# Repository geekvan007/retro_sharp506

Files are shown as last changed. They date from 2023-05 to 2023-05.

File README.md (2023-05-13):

# retro_sharp506
Retro an old-school calculator, using LED and mechanical keyboard

For several years, I am seeking a scientific calculator with a big screen
and keyboard but never found, so I decide to make a retro one.

It's not an emulator but a "real" machine, wish you like it.


[Full image](https://postimg.cc/0rZ6tzN7)


[Full image](https://postimg.cc/KRz1CmKw)


[Full image](https://postimg.cc/crbvSPwH)


[Full image](https://postimg.cc/rDRKFgN9)

[and here is the video](https://www.youtube.com/shorts/Iv_z6_ydeSI)

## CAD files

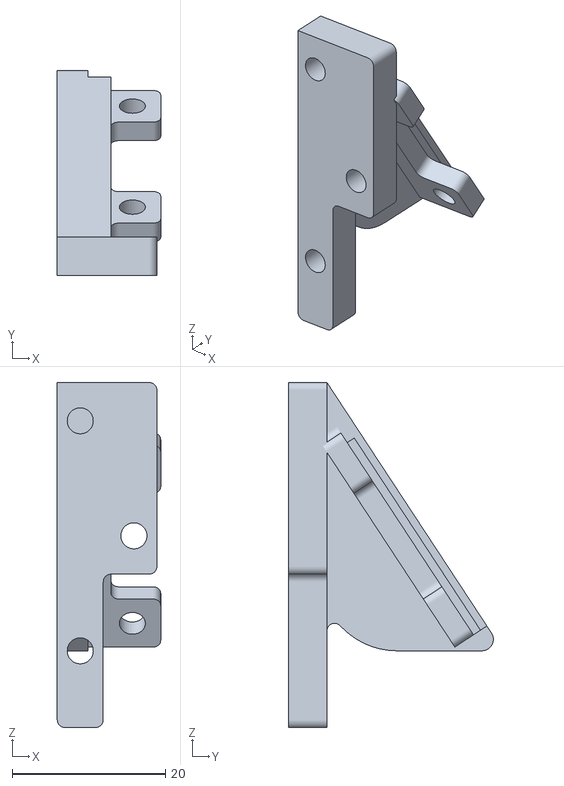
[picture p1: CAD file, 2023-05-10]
cad/left_bracket_v1.1.stl
13.5 x 26.7 x 45.0

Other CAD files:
cad/right_bracket_v1.1.stl
cad/bracket.sldprt

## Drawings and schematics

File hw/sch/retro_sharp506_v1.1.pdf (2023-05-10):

37 | SEG12 38 | SEG11 39 | SEG10 40 | SEG9 41 | SEG8 42 | SEG7 43 | SEG6 44 | SEG5 45 | SEG4 46 | SEG3 47 | COM2 48 | COM1
24 SEG24 | 23 SEG25 | 22 SEG26 | 21 COM27 | 20 COM28 | 19 GND | 18 COL10 | 17 COL9 | 16 COL8 | 15 COL7 | 14 COL6 | 13 COL5 ²⁵ SEG²3

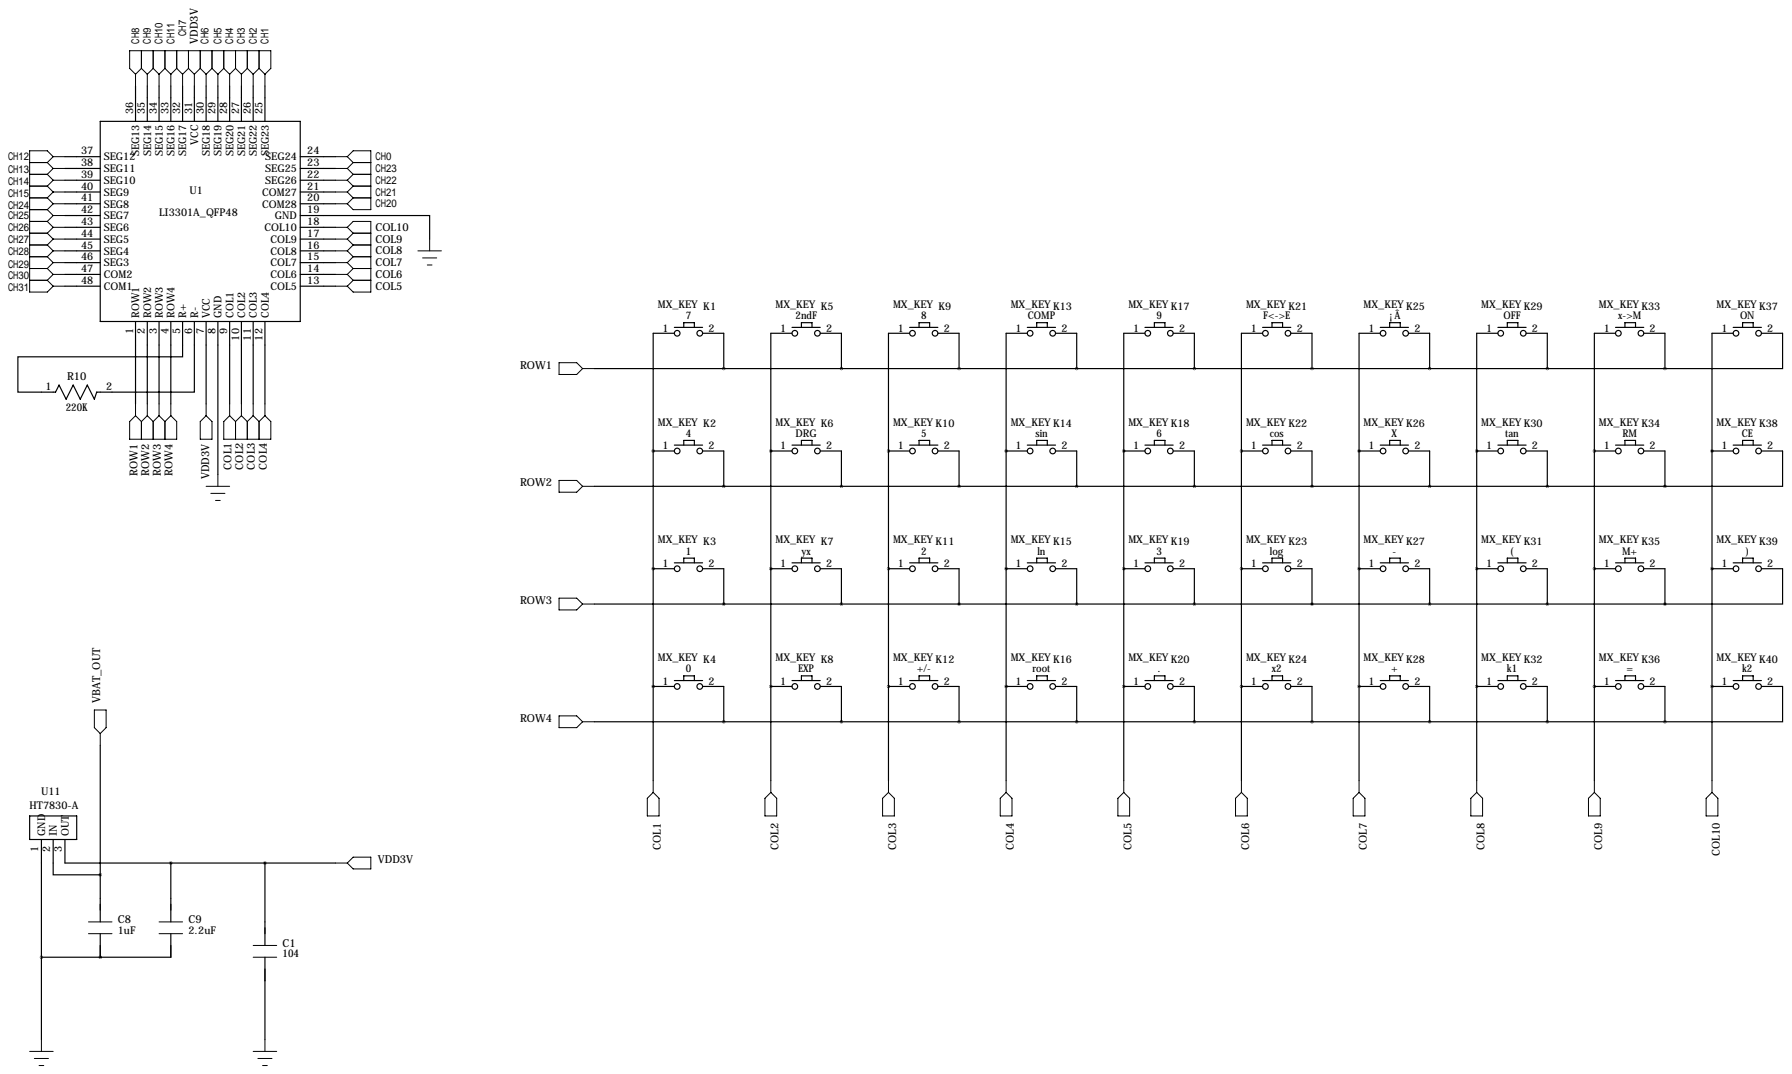
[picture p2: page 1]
26 SEG22 27 SEG21; 28 SEG20 29 SEG19; 30 SEG18 31 VCC; 32 SEG17; 33 SEG16 34 SEG15; 35 SEG14; 36 SEG13; 12 COL4; 11 COL3 10 COL2 9 COL1 8 GND 7 VCC 6 R-; 4 ROW4; 3 ROW3 2 ROW2 1 ROW1; LI3301A_QFP48; MX_KEY K1 7 1; MX_KEY K2 4 1; MX_KEY K3 1 1; MX_KEY K4 0; MX_KEY K5 2ndF; MX_KEY K6 DRG; MX_KEY K7 yx; MX_KEY K8 EXP; MX_KEY K9 8 1; MX_KEY K10 5 1; MX_KEY K11 2 1; MX_KEY K12 +/-; MX_KEY K13 COMP; MX_KEY K14 sin; MX_KEY K15 ln; MX_KEY K16 root; MX_KEY K17 9 1; MX_KEY K18 6 1; MX_KEY K19 3 1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

1 GND 2 IN 3 OUT

# JTAG_5X2_2.54 12345678 J2 SIP8_COM

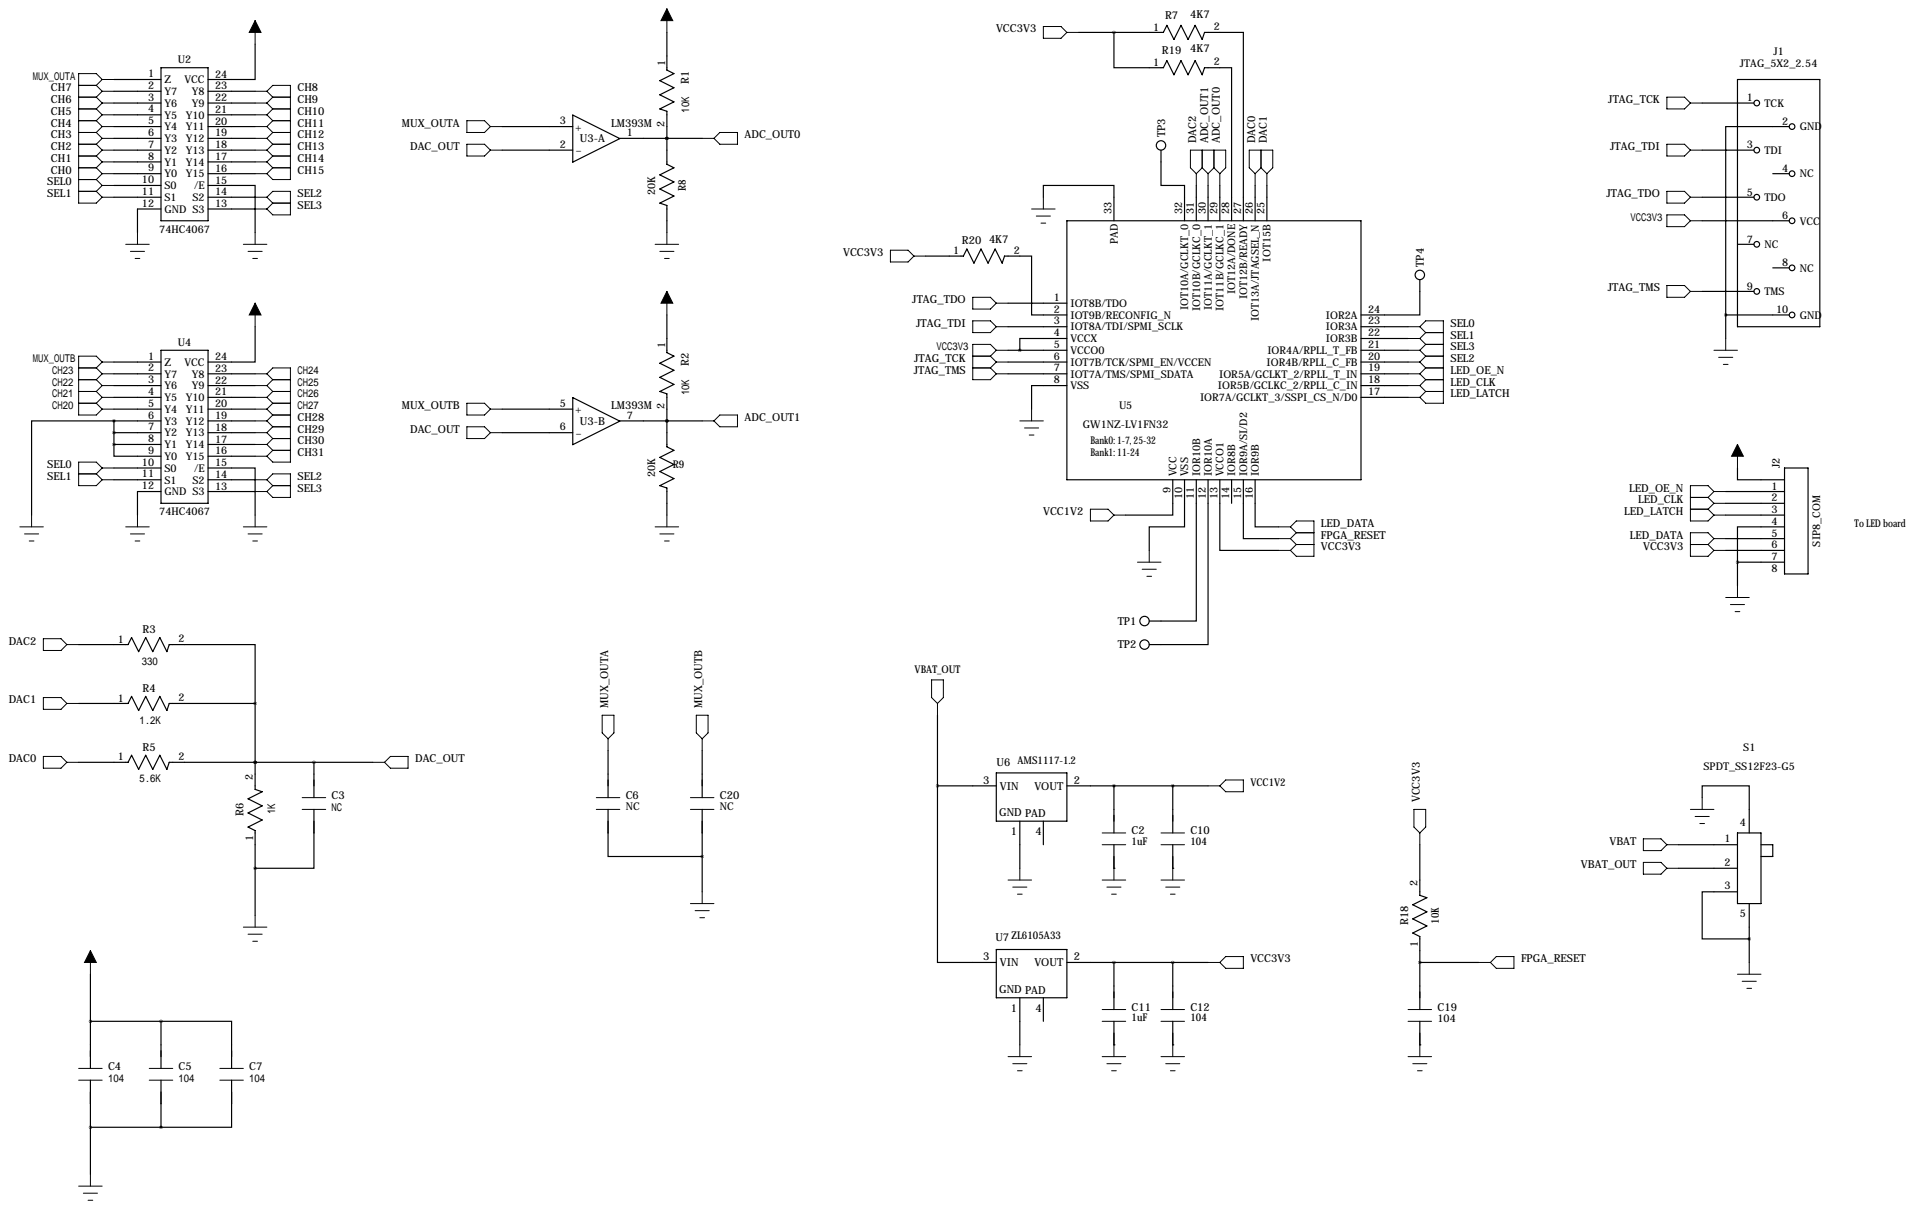
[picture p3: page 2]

7 | 18 Y13
8 | 17 Y14
9 | 16 Y15

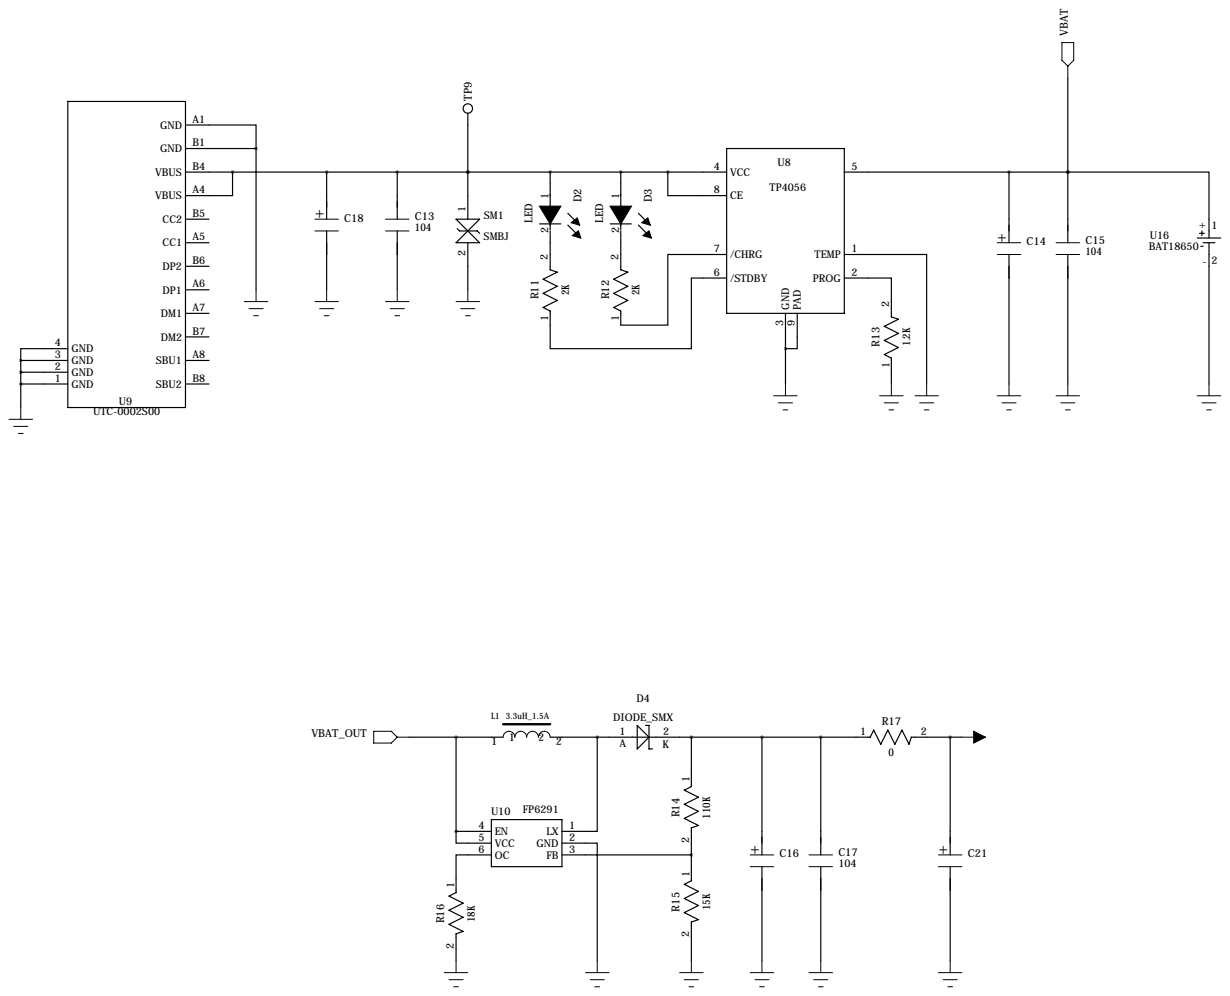
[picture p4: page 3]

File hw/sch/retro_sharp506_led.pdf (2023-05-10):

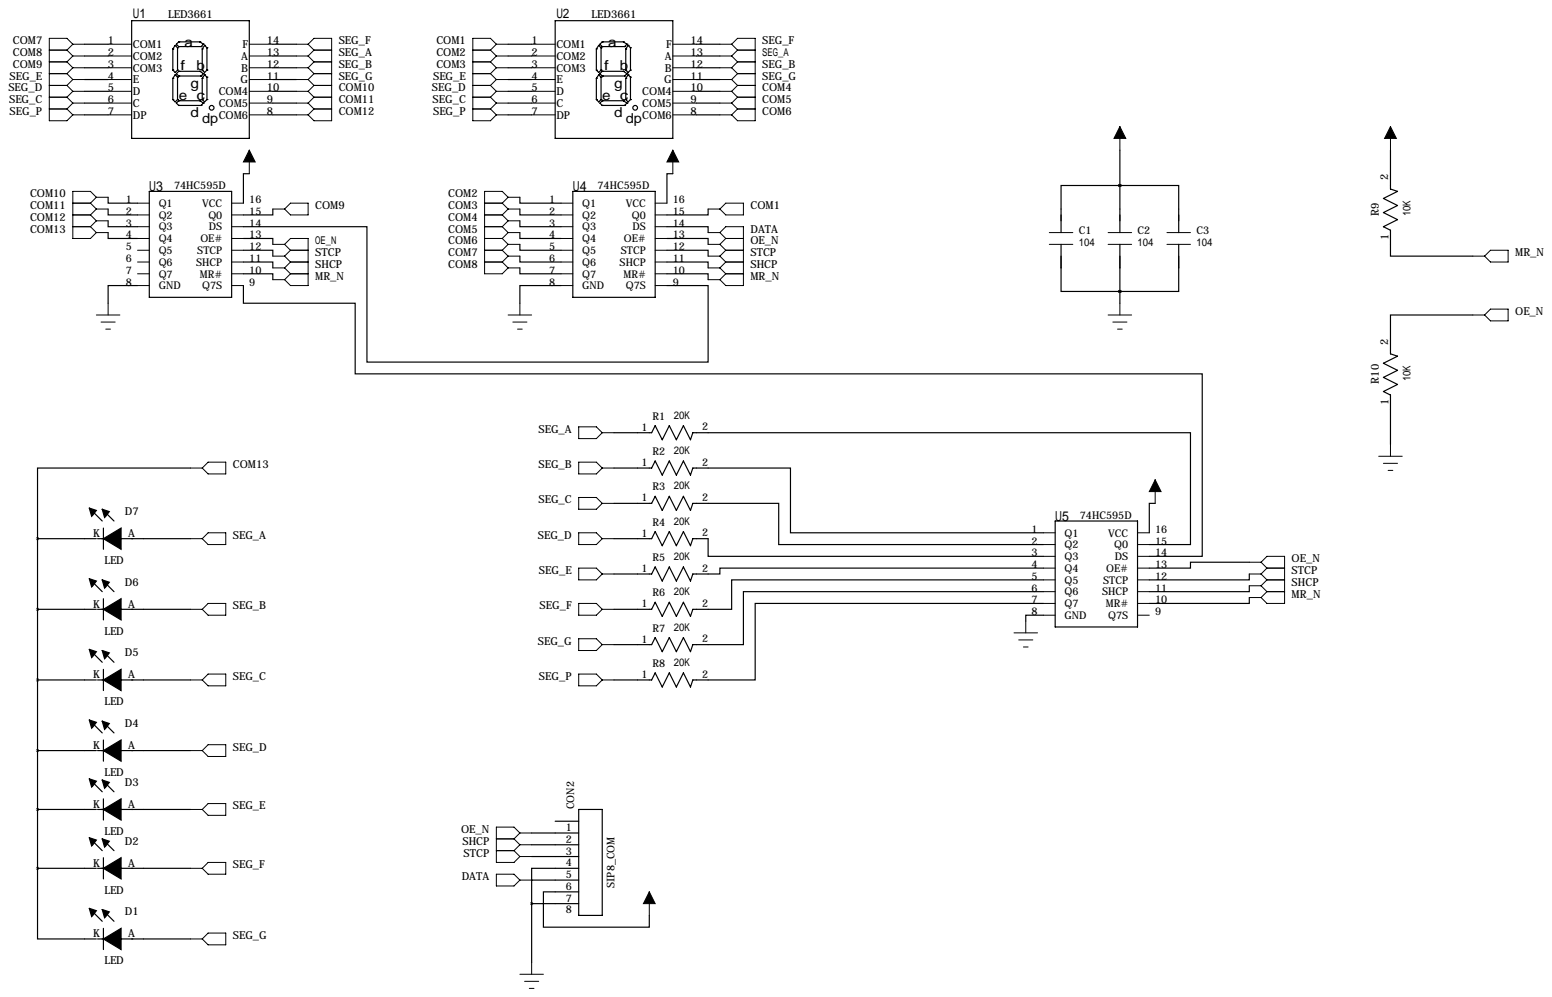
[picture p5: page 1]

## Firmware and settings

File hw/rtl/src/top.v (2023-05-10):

//`define DEBUG_MODE

// 7-seg digital bitmap
//     AAAA         ; A = 8'h01;
//    F    B        ; B = 8'h02;
//    F    B        ; C = 8'h04;
//     GGGG         ; D = 8'h08;
//    E    C        ; E = 8'h10;
//    E    C        ; F = 8'h20;
//     DDDD P       ; G = 8'h40;
//                  ; P = 8'h80;

// symbols @ COM0-COM11
`define SYM7_0 8'h3F
`define SYM7_1 8'h06
`define SYM7_2 8'h5B
`define SYM7_3 8'h4F
`define SYM7_4 8'h66
`define SYM7_5 8'h6D
`define SYM7_6 8'h7D
`define SYM7_7 8'h07
`define SYM7_8 8'h7F
`define SYM7_9 8'h6F
`define SYM7_A 8'h77
`define SYM7_B 8'h7C
`define SYM7_C 8'h39
`define SYM7_D 8'h5E
`define SYM7_E 8'h79
`define SYM7_F 8'h71
`define SYM7_R 8'h50
`define SYM7_O 8'h5C

`define SYM7_MINUS 8'h40
`define SYM7_DOT   8'h80
`define SYM7_BLANK 8'h00

// State icon @ COM12
`define ICON_LRN  8'h01
`define ICON_STAT 8'h02
`define ICON_MEM  8'h04
`define ICON_ERR  8'h08
`define ICON_GRAD 8'h10
`define ICON_RAD  8'h20
`define ICON_DEG  8'h40

// COM bitmap
// S 888888 888888
// C 6789AB 012345
`define COM_DIG0   5
`define COM_DIG1   4
`define COM_DIG2   3
`define COM_DIG3   2
`define COM_DIG4   1
`define COM_DIG5   0
`define COM_DIG6  11
`define COM_DIG7  10
`define COM_DIG8  19
`define COM_DIG9   8
`define COM_DIG10  7
`define COM_DIG11  6
`define COM_ICON  12

module SHARP506_TOP (
	input        reset_n,
	output [3:0] adc_ch,
	output [2:0] dac_out,
	input  [1:0] adc_in,

	output       led_oe_n,
	output       led_clk,
	output       led_latch,
	output       led_data,

	output [2:0] debug_o
);

wire osc_clk; // on chip OSC
wire sys_clk;
wire adc_clk;
wire off_clk; // lcd off detection
wire busy_clk; // lcd busy detection
wire sys_reset;

wire sys_reset_n = reset_n;
//wire sys_reset_n = 1'b1;

assign sys_reset = ~sys_reset_n;

wire power_off;
wire calc_busy;

//------------------------------------------------------------------------------

// 250M / div
OSCZ osc_inst (
	.OSCOUT(osc_clk),
	.OSCEN(1'b1)
);
defparam osc_inst.FREQ_DIV = 100;
defparam osc_inst.S_RATE   = "SLOW";

//------------------------------------------------------------------------------

MCLK_DIVX sys_clk_div(
	.clk(osc_clk),
	.sys_reset_n(sys_reset_n),
	.clk_div2(),
	.clk_div4(), // 625k
	.clk_div8(sys_clk), // 312k
	.clk_div16(), // 156k
	.clk_div32(adc_clk), // 78k
	.clk_div64(off_clk) // 39k
);

assign busy_clk = off_clk;
//assign adc_clk = sys_clk;
//assign adc_clk = off_clk;

//------------------------------------------------------------------------------

OFF_DETECTOR u_off_det (
	.clk(off_clk),
	.sys_reset_n(sys_reset_n),
	.sample_i(adc_in),
	.power_off(power_off)
);

//------------------------------------------------------------------------------

wire       adc_sample;
wire       adc_write_en;
wire [6:0] adc_write_addr;
wire [1:0] adc_com_raw;
wire [2:0] adc_debug;

assign debug_o[0] = calc_busy;//adc_debug[2];
//assign debug_o[1] = adc_write_en;
//assign debug_o[2] = adc_sample;
assign debug_o[1] = adc_debug[0];
assign debug_o[2] = adc_debug[1];

// adc
ADC2_32CH u_adc2 (
	.clk(adc_clk),
	.sys_reset_n(sys_reset_n),
	.ch_sel_o(adc_ch),
	.dac_o(dac_out),
	.sample_i(adc_in),
	.write_en(adc_write_en),
	.write_addr(adc_write_addr),
	.sample_o(adc_sample),
	.com_raw_o(adc_com_raw),
	.debug_o(adc_debug)
);

//------------------------------------------------------------------------------

BUSY_DETECTOR u_busy_det (
	.clk(busy_clk),
	.sys_reset_n(sys_reset_n),
	.sample_i(adc_com_raw),
	.busy(calc_busy)
);

// 0: disp on
// 1: disp off
`ifdef DEBUG_MODE
assign led_oe_n = 1'b0;
`else
assign led_oe_n = power_off | calc_busy;
`endif

//------------------------------------------------------------------------------

// remap bits
wire        prom_clk;
wire [ 6:0] prom_addr;
wire [ 7:0] prom_dout;
wire [23:0] prom_dout_w;

assign prom_clk  = adc_clk;
assign prom_addr = adc_write_addr;

pROM prom_inst_0 (
	.DO({prom_dout_w[23:0], prom_dout[7:0]}),
	.CLK(prom_clk),
	.OCE(1'b1),
	.CE(1'b1),
	.RESET(sys_reset),
	.AD({4'd0, prom_addr[6:0], 3'd0})
);

defparam prom_inst_0.READ_MODE   = 1'b0;
defparam prom_inst_0.BIT_WIDTH   = 8;
defparam prom_inst_0.RESET_MODE  = "SYNC";
// remap LCD seg-com to LED
defparam prom_inst_0.INIT_RAM_00 = 256'h7F_7F_60_61_3D_38_45_40_2D_28_7F_7F_7F_7F_7F_7F__4D_48_55_50_00_05_58_5D_0D_08_15_10_1D_18_25_20;
defparam prom_inst_0.INIT_RAM_01 = 256'h7F_7F_64_62_3E_39_46_41_2E_29_7F_7F_7F_7F_7F_7F__4E_49_56_51_01_06_59_5E_0E_09_16_11_1E_19_26_21;
defparam prom_inst_0.INIT_RAM_02 = 256'h7F_7F_65_36_3C_3A_44_42_2C_2A_7F_7F_7F_7F_7F_7F__4C_4A_54_52_02_04_5A_5C_0C_0A_14_12_1C_1A_24_22;
defparam prom_inst_0.INIT_RAM_03 = 256'h7F_7F_66_63_3B_3F_43_47_2B_2F_7F_7F_7F_7F_7F_7F__4B_4F_53_57_07_03_5F_5B_0B_0F_13_17_1B_1F_23_27;

//------------------------------------------------------------------------------

wire       dbuf_w_clk;
wire [6:0] dbuf_w_addr;
wire       dbuf_w_data;
wire       dbuf_w_en;

wire       dbuf_r_clk;
wire [3:0] dbuf_r_addr;
wire [7:0] dbuf_r_data;

wire [23:0] sdpb_inst_0_dout_w; // unused

assign dbuf_w_clk  = adc_clk;
`ifdef DEBUG_MODE
assign dbuf_w_en   = 1'b0;
//assign dbuf_w_en   = adc_write_en;
`else
assign dbuf_w_en   = adc_write_en;
`endif
//assign dbuf_w_addr = adc_write_addr; // directly, for debug only
assign dbuf_w_addr = prom_dout[6:0]; // lookup
assign dbuf_w_data = adc_sample;

assign dbuf_r_clk  = sys_clk;

SDPB sdpb_inst_0 (
	.RESETA(sys_reset),
	.CEA(dbuf_w_en),
	.CLKA(dbuf_w_clk),
	.BLKSELA(3'b000),
	.ADA({7'd0, dbuf_w_addr[6:0]}),
	.DI({31'd0, dbuf_w_data}),

	.RESETB(sys_reset),
	.CEB(1'b1),
	.CLKB(dbuf_r_clk),
	.BLKSELB(3'b000),
	.ADB({7'd0, dbuf_r_addr[3:0], 3'b000}),
	.DO({sdpb_inst_0_dout_w[23:0], dbuf_r_data[7:0]}),

	.OCE(1'b1)
);

defparam sdpb_inst_0.READ_MODE   = 1'b0;
defparam sdpb_inst_0.BIT_WIDTH_0 = 1;
defparam sdpb_inst_0.BIT_WIDTH_1 = 8;
defparam sdpb_inst_0.BLK_SEL_0   = 3'b000;
defparam sdpb_inst_0.BLK_SEL_1   = 3'b000;
defparam sdpb_inst_0.RESET_MODE  = "SYNC";
`ifdef DEBUG_MODE
// display digitals at startup for test.
defparam sdpb_inst_0.INIT_RAM_00 = 256'h00000000_00000000_00000000_00000000_0000007F_6D664F5B_063F7C77_6F7F077D;
`endif

//------------------------------------------------------------------------------

wire [31:0] hc595_data;

HC595X3 u_595x3 (
	.clk(sys_clk),
	.sys_reset_n(sys_reset_n),
	.data_i(hc595_data),
	.shcp(led_clk),
	.stcp(led_latch),
	.data_o(led_data)
);

LED_CONTROLLER u_led_ctrl (
	.clk(sys_clk),
	.sys_reset_n(sys_reset_n),
	.char_clk(),
	.addr_o(dbuf_r_addr),
	.data_i(dbuf_r_data),
	.data_o(hc595_data)
);

endmodule

//==============================================================================

module MCLK_DIVX (
	input clk,
	input sys_reset_n,

	output clk_div2,
	output clk_div4,
	output clk_div8,
	output clk_div16,
	output clk_div32,
	output clk_div64
);

reg [5:0] clk_cnt = 0;

always@(posedge clk or negedge sys_reset_n) begin
	if (~sys_reset_n)
		clk_cnt <= 0;
	else
		clk_cnt <= clk_cnt + 6'b1;
end
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
